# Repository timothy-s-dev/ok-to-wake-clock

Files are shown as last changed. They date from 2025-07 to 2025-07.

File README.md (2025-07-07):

# OK-to-Wake Clock - ESP32 Multi-Function Clock

This project provides code for a digital OK-to-Wake clock using an ESP32 with
multiple input and output components. The clock includes rotary encoder input
(w/ switch), RGB LED state indicator, alphanumeric display, and an RTC with
battery backup so the time is not lost when power is.

A schedule can be set for each day of the week, with the following time windows:

* Wind Down (Blue)
* Sleep (Red)
* Quiet (Yellow)
* Wake (White)

Depending on which window the current time falls in for the current day's
schedule the RGB LED will change colors.

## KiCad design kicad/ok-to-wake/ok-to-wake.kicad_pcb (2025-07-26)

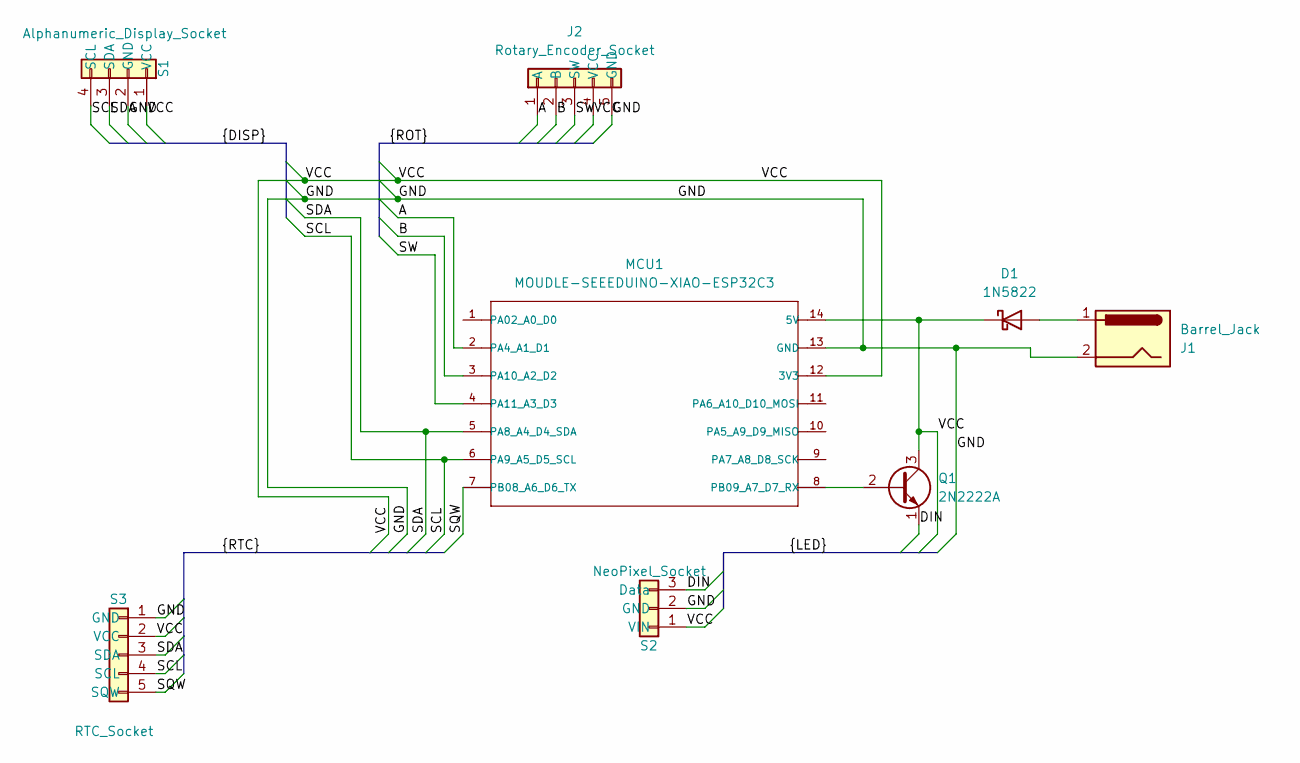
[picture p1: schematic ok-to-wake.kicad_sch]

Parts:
D1: 1N5822; D_DO-201AD_P15.24mm_Horizontal
J1: Barrel_Jack; JST_XH_B2B-XH-A_1x02_P2.50mm_Vertical
J2: Rotary_Encoder_Socket; JST_XH_B5B-XH-AM_1x05_P2.50mm_Vertical
MCU1: MOUDLE-SEEEDUINO-XIAO-ESP32C3; MCU_Seeed_ESP32C3
Q1: 2N2222A; TO-92
S1: Alphanumeric_Display_Socket; JST_XH_B4B-XH-AM_1x04_P2.50mm_Vertical
S2: NeoPixel_Socket; JST_XH_B3B-XH-AM_1x03_P2.50mm_Vertical
S3: RTC_Socket; PinHeader_1x05_P2.54mm_Vertical

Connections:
/A: J2.1 (A), MCU1.2 (PA4_A1_D1)
/B: J2.2 (B), MCU1.3 (PA10_A2_D2)
/DIN: Q1.1 (E), S2.3 (Data)
/GND: J1.2, J2.5 (GND), MCU1.13 (GND), S1.2 (GND), S2.2 (GND), S3.1 (GND)
/SCL: MCU1.6 (PA9_A5_D5_SCL), S1.4 (SCL), S3.4 (SCL)
/SDA: MCU1.5 (PA8_A4_D4_SDA), S1.3 (SDA), S3.3 (SDA)
/SQW: MCU1.7 (PB08_A6_D6_TX), S3.5 (SQW)
/SW: J2.3 (SW), MCU1.4 (PA11_A3_D3)
/VCC: D1.1 (K), J2.4 (VCC), MCU1.12 (3V3), MCU1.14 (5V), Q1.3 (C), S1.1 (VCC), S2.1 (VIN), S3.2 (VCC)
unnamed: D1.2 (A), J1.1
unnamed: MCU1.8 (PB09_A7_D7_RX), Q1.2 (B)

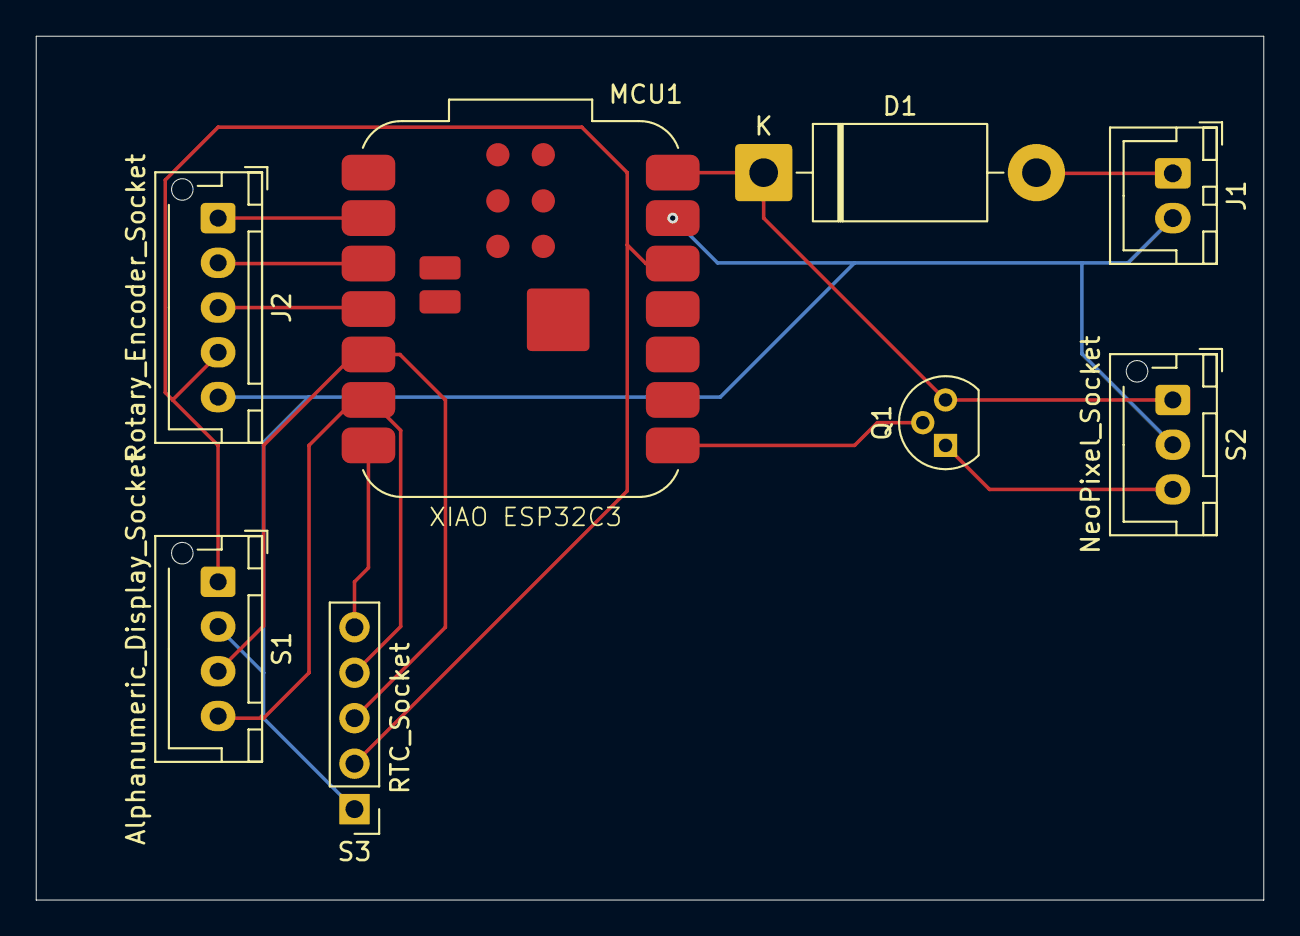
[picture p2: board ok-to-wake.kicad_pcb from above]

Board: 2 copper layers, 68.6 x 48.3 mm, 8 parts (0 on the bottom side), 11 nets.

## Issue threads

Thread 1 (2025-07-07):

Set current date from device

timothy-s-dev, 2025-07-07:
There needs to be a way to set the current date on the clock using the rotary encoder, so that the clock can know which day's schedule to use. There will likely need to be special consideration for the transition between days at midnight. (E.G. Do I use the "Sleep End" time from Friday or Saturday if it's currently Saturday morning?)

timothy-s-dev, 2025-07-09:
Not needed, this is sync'd automatically

Closed 2025-07-09.

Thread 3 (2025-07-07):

Allow Locking the Device

timothy-s-dev, 2025-07-07:
There should be a way to lock the device so that it no longer responds to inputs on the rotary encoder until some specific input is detected (E.G. Holding the switch for 5 seconds). There's no way my kid doesn't tamper with it, so it should be at least somewhat resistant to that.

Closed 2025-07-12.

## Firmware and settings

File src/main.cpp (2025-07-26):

#include <Arduino.h>
#include <Wire.h>
#include "state_machine.h"
#include "display.h"
#include "encoder.h"
#include "clock.h"
#include "settings.h"
#include "rgbled.h"
#include "logging.h"

#define SCL_PIN 6
#define SDA_PIN 5

#define RTC_SQW_PIN 43

// 32KB EEPROM
#define EEPROM_I2C_ADDR 0x57
#define RTC_I2C_ADDR 0x68

void setup() {
  Serial.begin(115200);

  delay(5000);
  
  // Initialize custom Log module - set to false to use Serial fallback
  Log::init(false);  
  Log::info("Starting Wake Clock...");

  Wire.begin(SDA_PIN, SCL_PIN);
  Wire.setBufferSize(512);
  Log::info("I2C initialized");

  // SCAN ALL I2C DEVICES
  Log::info("Checking for RTC");
  Wire.beginTransmission(RTC_I2C_ADDR);
  if (Wire.endTransmission() != 0) {
    Log::error("RTC not found!");
  } else {
    Log::info("RTC found!");
  }
  Log::info("Checking for Display");
  Wire.beginTransmission(0x70);
  if (Wire.endTransmission() != 0) {
    Log::error("Display not found!");
  } else {
    Log::info("Display found!");
  }

  if (!Settings::init()) {
    Log::error("Failed to initialize settings!");
  }

  Clock::init(RTC_SQW_PIN);
  Clock::enableSQWInterrupt();
  RgbLed::init();
  Display::init();
  Encoder::init();
  StateMachine::init();

  Clock::updateScheduleLED();
}

void loop() {
  Clock::update();  
  Action action = Encoder::getAction();
  StateMachine::processAction(action);
  delay(10);
}

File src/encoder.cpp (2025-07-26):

#include "encoder.h"
#include "logging.h"

#define DIAL_CLK_PIN 2
#define DIAL_DT_PIN 3
#define DIAL_SW_PIN 4

ESP32Encoder encoder;

volatile bool Encoder::buttonPressed;
volatile unsigned long Encoder::lastButtonTime;
volatile bool Encoder::lastButtonState;
volatile bool Encoder::buttonStateStable;
unsigned long Encoder::buttonPressStartTime = 0;
bool Encoder::buttonHoldDetected = false;
const unsigned long BUTTON_DEBOUNCE_MS = 50;
const unsigned long BUTTON_HOLD_MS = 3000; // 3 seconds

void IRAM_ATTR Encoder::buttonISR() {
  lastButtonTime = millis();
}

void Encoder::init() {
  encoder.attachSingleEdge(DIAL_DT_PIN, DIAL_CLK_PIN);
  encoder.setCount(0);

  pinMode(DIAL_SW_PIN, INPUT_PULLUP);
  attachInterrupt(digitalPinToInterrupt(DIAL_SW_PIN), buttonISR, CHANGE);
}

Action Encoder::getAction() {
  static int64_t lastEncoderCount = 0;
  int64_t currentCount = encoder.getCount();
  
  Action action = NONE;
  
  // Check for rotation
  if (currentCount > lastEncoderCount) {
    action = CW;
    lastEncoderCount = currentCount;
  } else if (currentCount < lastEncoderCount) {
    action = CCW;
    lastEncoderCount = currentCount;
  }
  
  // Software debouncing for button
  static unsigned long lastDebounceTime = 0;
  bool currentButtonState = digitalRead(DIAL_SW_PIN);
  
  if (currentButtonState != lastButtonState) {
    lastDebounceTime = millis();
  }
  
  if ((millis() - lastDebounceTime) > BUTTON_DEBOUNCE_MS) {
    if (currentButtonState != buttonStateStable) {
      buttonStateStable = currentButtonState;
      
      // Button pressed (transition from HIGH to LOW)
      if (buttonStateStable == LOW) {
        buttonPressStartTime = millis();
        buttonHoldDetected = false;
        // Trigger SELECT immediately on button press
        action = SELECT;
      }
      // Button released (transition from LOW to HIGH)
      else if (buttonStateStable == HIGH) {
        unsigned long pressDuration = millis() - buttonPressStartTime;
        
        // Trigger SELECT_HOLD on release if held for 3+ seconds
        if (pressDuration >= BUTTON_HOLD_MS) {
          action = SELECT_HOLD;
        }
        
        buttonHoldDetected = false;
        buttonPressStartTime = 0;
      }
    }
  }
  
  lastButtonState = currentButtonState;
  
  return action;
}

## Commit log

2025-07-26 Add kicad files
    [freerouting.dsn, ok-to-wake.kicad_pcb, ok-to-wake.kicad_sch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]
2025-07-26 Switch to Seeed XIAO ESP32S3 and Adafruit NeoPixel
